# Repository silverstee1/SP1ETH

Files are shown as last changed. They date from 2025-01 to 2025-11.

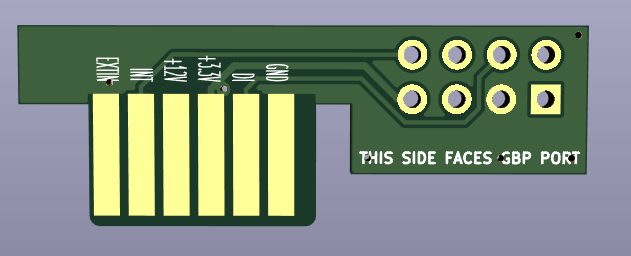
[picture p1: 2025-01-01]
pcb/pcb.png

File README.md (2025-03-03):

# SP1ETH
DIY Adapter PCB and Case for SP1 on the Nintendo Gamecube for a ENC28J60 BBA based on the ETH2GC project by webhdx & Extrems

Must be used with the lastest version of Swiss as of 1788 in order to use the in game BBA features as it supports the hypervisor driver for games.

20250101_160555-min

**PCB**

Must be ordered from fab such as jlcpcb with 1.2mm thickness with ENIG surface finish

I used 10CM Female to Male dupont wires to connect the ENC28J60 Mini to the pcb but regular wires can be directly soldered to the pcb and ENC28J60 as well, make sure to follow the pinout below.

I also removed the little black retaining plastic on the ENC28J60 in order to push the dupont connectors closer to the pcb to allow more clearance when closing the case together but you can bend the pins some as I did in the images to help with the 2 case halves closing better.

If using the 10Pin IDC cable instead of dupont wires there's no need to remove the black retaining plastic on the module as the IDC connector is short enough to close the 2 case halves together.

The case is designed to just snap together without any hardware, printed on an FDM 3D printer in something stronger than PLA, I've used PLA+ as its less brittle.

**BOM**

| Item | Source |
| --- | --- |
| ENC28J60 Mini | https://www.aliexpress.us/item/2255800100119709.html |
| 10CM Dupont Female to Male Wires or 10Pin female IDC cable | Amazon/Aliexpress |
| 1.2MM PCB | JLCPCB/Fab House |
| Case Shell | 3D Printed |
| Optional 20x6x2mm Oval Rubber Foot | https://www.aliexpress.us/item/3256807864916472.html |

**Pinout**

| ENC28J60 | Connector PCB |
| --- | --- |
| GND | GND |
| VCC | 3v3 |
| CS | CS |
| SCK | CLK |
| SO | DI |
| SI | DO |
| INT | INT |

Pinout

pcb

ENC28J60IDC-min

20250125_231507-min

20250101_144940-min

20250101_145106-min

20250101_145139-min

20250101_145732-min

20250101_151721-min

20250101_160413-min

20250101_160510-min

20250101_160601-min

20250101_160623-min

20250101_160939(0)-min

rubberfoot-min

20250101_164624-min

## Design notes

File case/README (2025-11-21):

case file remixed from https://www.thingiverse.com/thing:6693459

The two parts are meant to be snapped together without any hardware, print using something stronger than PLA, I used PLA+ as it was less brittle and prone to snapping unlike regular PLA.

v3.3 of the insert case piece has grippers added to the model to improve fitment with the SP1 metal retaining springs on the gamecube for a more stable/better fit.

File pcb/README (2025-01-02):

must be ordered in 1.2mm thickness ENIG surface finish

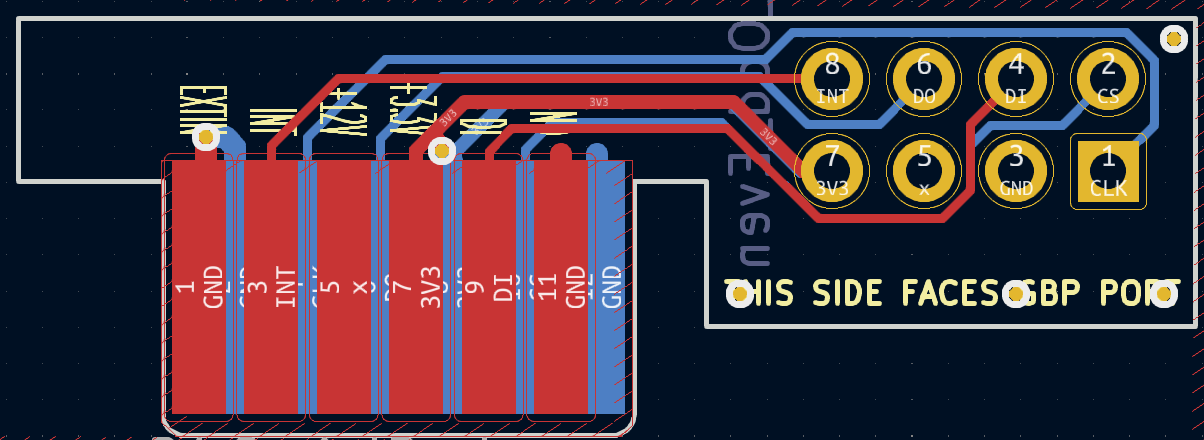
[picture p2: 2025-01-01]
pcb/Pinout.png

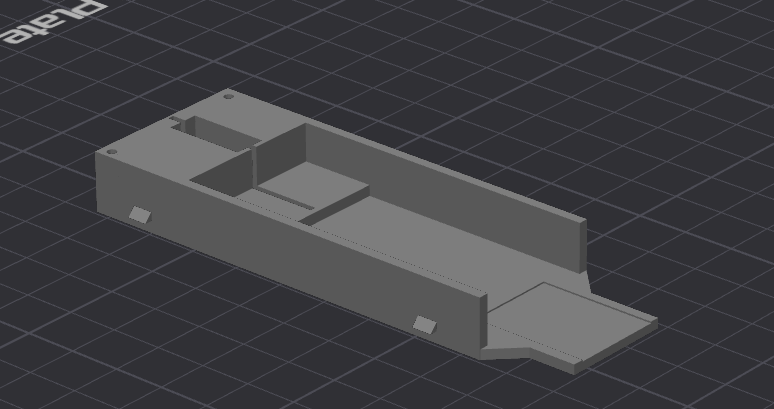
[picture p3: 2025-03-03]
case/pics/ImageInsert3.1.png

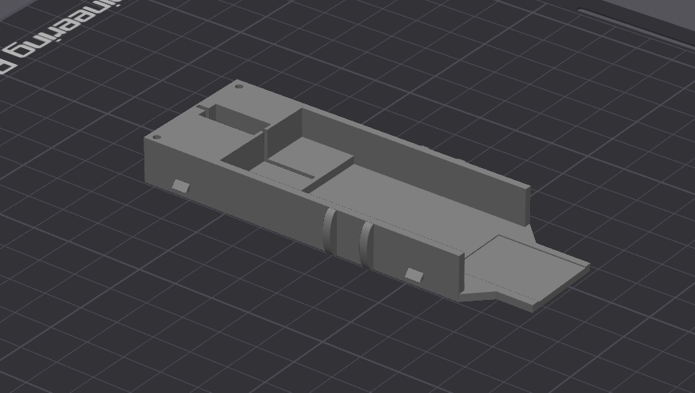
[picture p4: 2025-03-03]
case/pics/ImageInsert3.2.png

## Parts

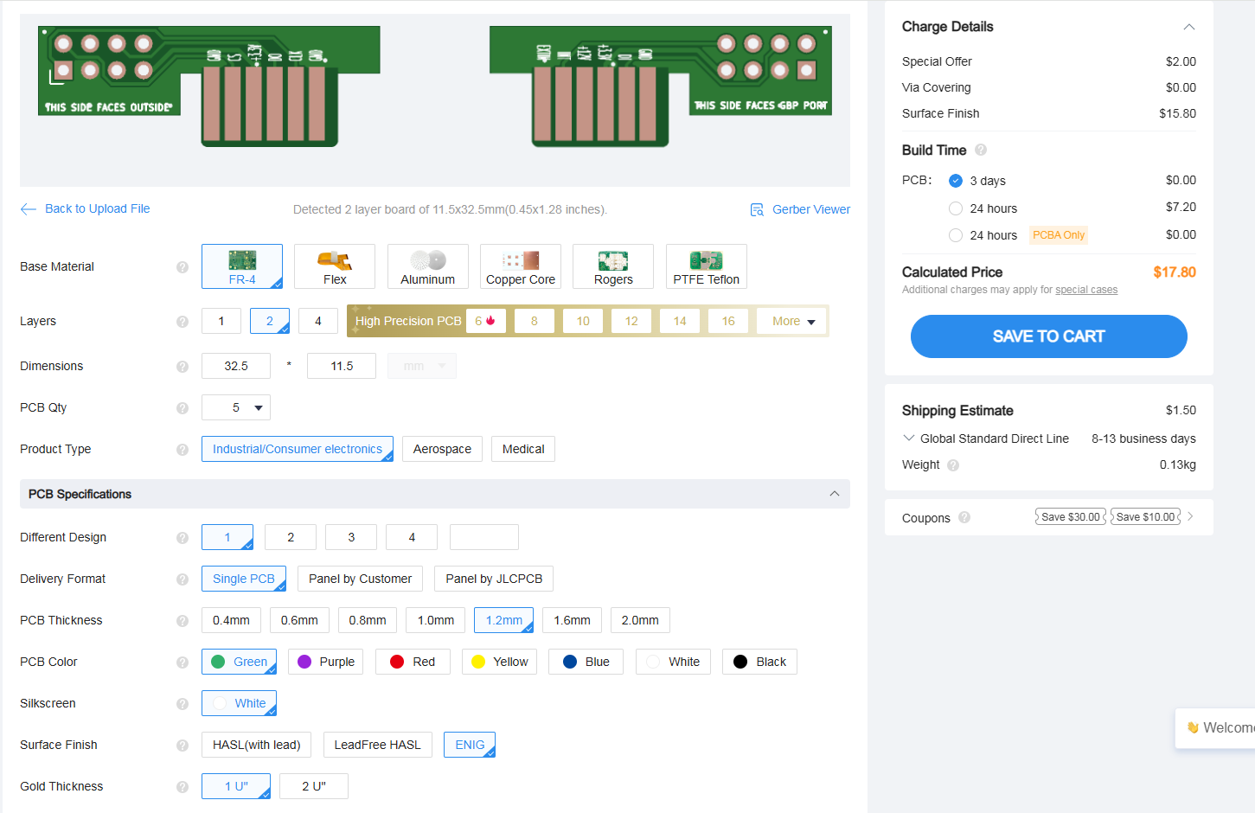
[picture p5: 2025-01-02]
pcb/example JLCPCB order.png

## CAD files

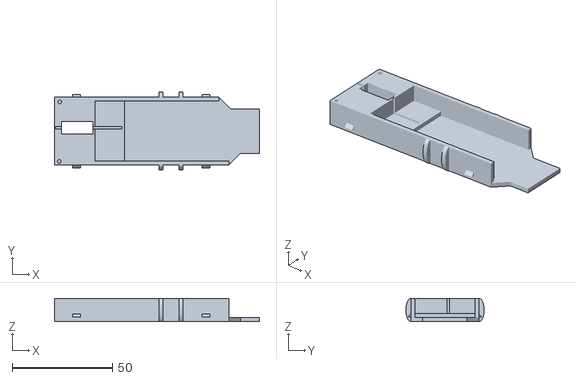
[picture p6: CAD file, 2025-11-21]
case/ENC18J60 Insertv3.3Grip.stl
102.1 x 39.0 x 11.6

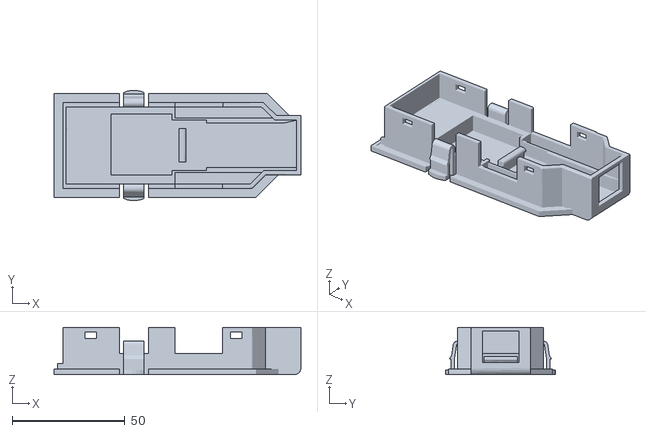
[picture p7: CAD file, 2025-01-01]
case/ENC18J60 InsertBottomv3.1.stl
109.5 x 48.9 x 21.0

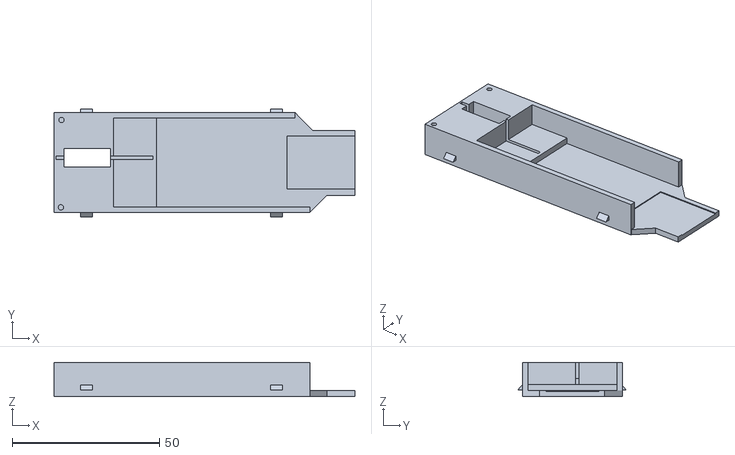
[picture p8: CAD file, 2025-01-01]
case/ENC18J60 Insertv3.1.stl
102.1 x 36.8 x 11.6

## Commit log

2025-01-01 added case STLs and pcb gerbers
    [ENC18J60 InsertBottomv3.1.stl, ENC18J60 Insertv3.1.stl]
2025-01-26 Update README.md
    added pics/pinout of 10pin IDC cable option instead of dupont wires
2025-02-01 added remade kicad project
    [ConnSP1.kicad_pcb, ConnSP1.kicad_sch]
2025-02-12 grippers added to insert
    added grippers to the insert piece to mate with the metal retaining springs inside the gamecube SP1 slot for a more better/stable fitment.
    [ENC18J60 Insertv3.2Grip.stl]
2025-03-03 Rename Image Insert 3.1.png to ImageInsert3.1.png
2025-03-03 Rename Image Insert 3.2.png to ImageInsert3.2.png
2025-11-21 Delete case/ENC18J60 Insertv3.2Grip.stl
    deleting old case file that had gaps in it
    [ENC18J60 Insertv3.2Grip.stl]
